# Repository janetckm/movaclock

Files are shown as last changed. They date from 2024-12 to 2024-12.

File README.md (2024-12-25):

# Movaclock： Clock with Movable Type
Project GIF

## Project Description
Movaclock is a clock installation inspired by the Chinese Movable-type system. Using 3D-printed models and mechanisms, Movaclock provides a tangible experience in the RBM Makerspace for time interface and cultural inheritance.

## Slides / About Movaclock 
[https://github.com/janetckm/movaclock/blob/main/powerpoint/movaclock_slides_EN.pdf](https://github.com/janetckm/movaclock/blob/9e4041c35f7cdca07a0c9aedfe9599291e075717/powerpoint/movaclock_slides_EN.pdf)

## Video Demonstration / User Guide
https://youtu.be/eYBHK9oxsUM

## Awards
Second Prize, Red Bird Makerspace Model Maker Compeition, Hong Kong University of Science and Technology (Guangzhou), China <br>
Second Prize, Tsinghua University 3D Competition, Tsinghua University, China

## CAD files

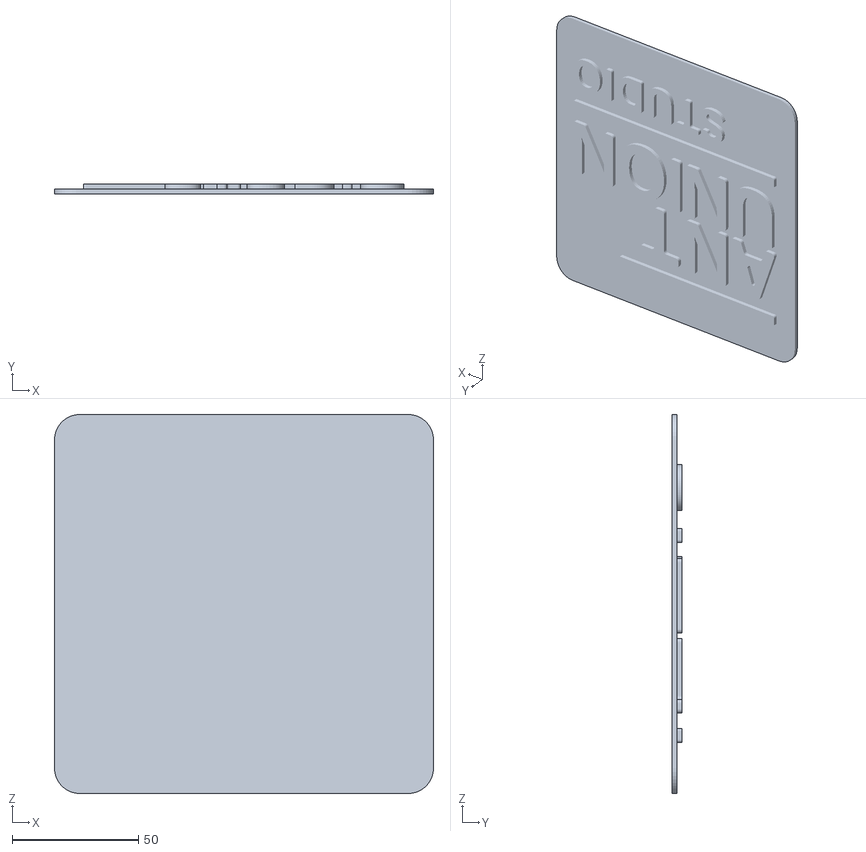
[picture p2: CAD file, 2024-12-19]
logo/printLogo.stl
150.0 x 4.00 x 150.0

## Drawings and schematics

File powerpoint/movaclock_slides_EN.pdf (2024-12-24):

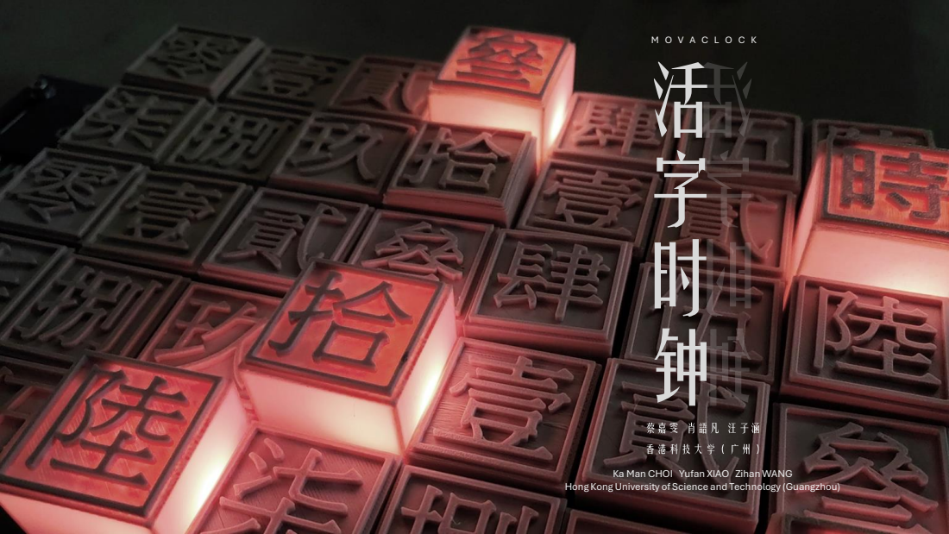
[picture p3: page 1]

Ka Man CHOI Yufan XIAO Zihan WANG

Hong Kong University of Science and Technology (Guangzhou)

背景 与 意义

将 文化传承 带入 日常生活
透过结合当代文创元素融合生活，设计与科技结合可以使传统工艺吸引更 多大眾關注与了解

创新 结合 传统工艺
活字印刷作为非物质文化遗产，结合3D打印和装置艺术，在实现创新的同 时，有助于保护和传承传统工艺

目标与内 容
活字 ＋时钟 ＋灯饰

启发自活字印刷术与2008年北京奥运开幕式的活字升降动态，而时间则 成为文字内容，包括「零、壹、貳、叄、肆、伍、陸、柒、捌、玖、拾」 和「时、分」; 配合灯光和可活动字块的升降，提升时间的可读性

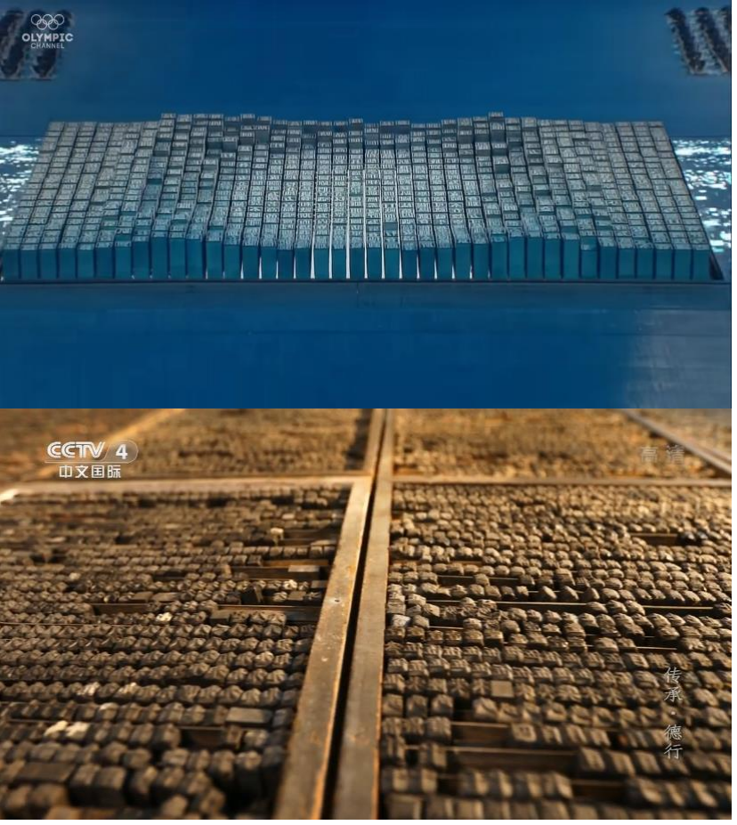
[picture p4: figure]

1. Opening Ceremony - Beijing 2008 Summer Olympic Games
2. [传承第二季] 木活字印刷术 | CCTV中文国际 Wood Movable Types, CCTV 4

Living Word + Clock + Lighting
Inspired by the movable type printing system and the opening ceremony of the 2008 Beijing Olympics, the movable type was developed with controlled movements, while the time becomes the content of the text, including "zero, one, two, two, four, five, six, seven, eight, nine, nine, ten" and "hour, minute“. With the lighting and the up and down of movable types, the readability of time is enhanced.

Objective
Movable Type + Clock + Light

Culture Interpretation

Bringing Cultural Heritage to Daily
Through the integration of cultural elements into daily life, the combination of design and technology can make traditional craftsmanship attract more public understanding
Technology and Craftsmanship
As an intangible cultural heritage, movable type combined with 3D printing and installation art can help convey traditional craftsmanship

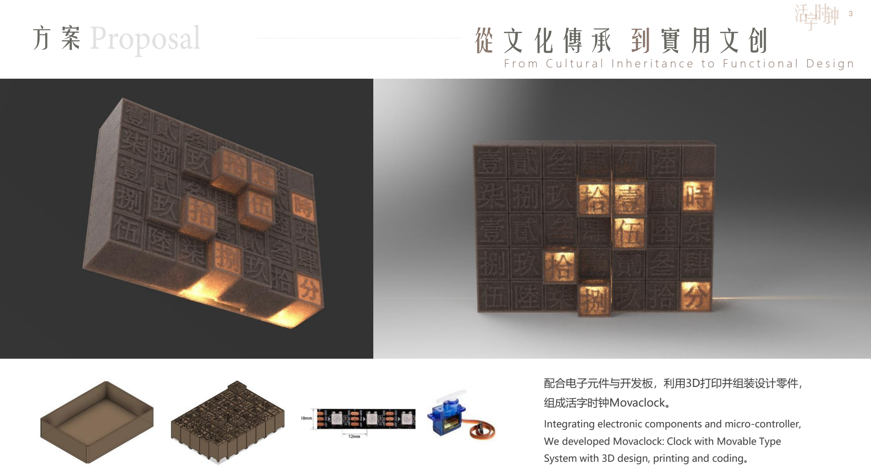
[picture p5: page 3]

配合电子元件与开发板，利用3D打印并组装设计零件，
组成活字时钟Movaclock。

Integrating electronic components and micro-controller, We developed Movaclock: Clock with Movable Type System with 3D design, printing and coding。

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

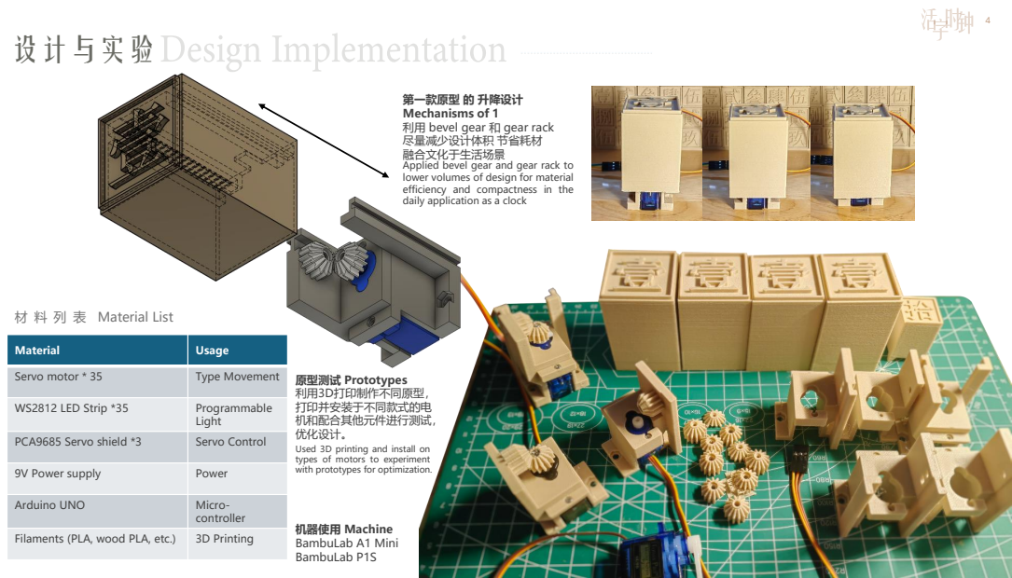
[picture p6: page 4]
机器使用 Machine BambuLab A1 Mini BambuLab P1S; Material List

第一款原型 的 升降设计
Mechanisms of 1
利用 bevel gear 和 gear rack
尽量减少设计体积 节省耗材
融合文化于生活场景
Applied bevel gear and gear rack to
lower volumes of design for material
efficiency and compactness in the
daily application as a clock

Material | Usage

Servo motor＊35 | Type Movement

原型测试 Prototypes
利用3D打印制作不同原型，
打印并安装于不同款式的电
机和配合其他元件进行测试，
优化设计。
Used 3D printing and install on
types of motors to experiment
with prototypes for optimization.

WS2812 LED Strip *35 | Programmable Light

PCA9685 Servo shield *3 | Servo Control

9V Power supply | Power

Arduino UNO | Micro-controller

Filaments (PLA, wood PLA, etc.) | 3D Printing

## PETG

## Wood PLA

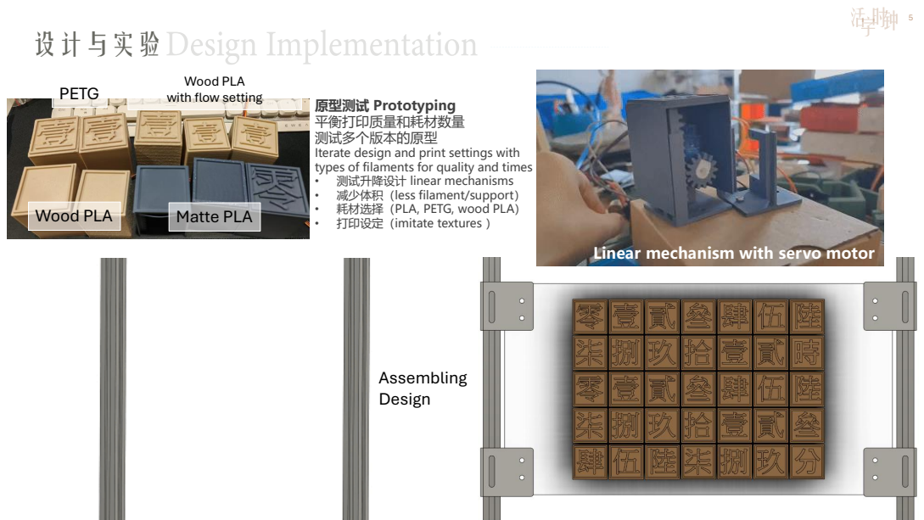
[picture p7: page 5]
耗材选择（PLA, PETG, wood PLA） Wood PLA; Matte PLA; 打印设定（imitate textures ）; Assembling Design

with flow setting

原型测试 Prototyping
平衡打印质量和耗材数量
测试多个版本的原型
Iterate design and print settings with
types of filaments for quality and times
• 测试升降设计 linear mechanisms
• 减少体积（less filament/support）

Linear mechanism with servo motor

## Arduino controls LEDs and motors to change the movements and effects

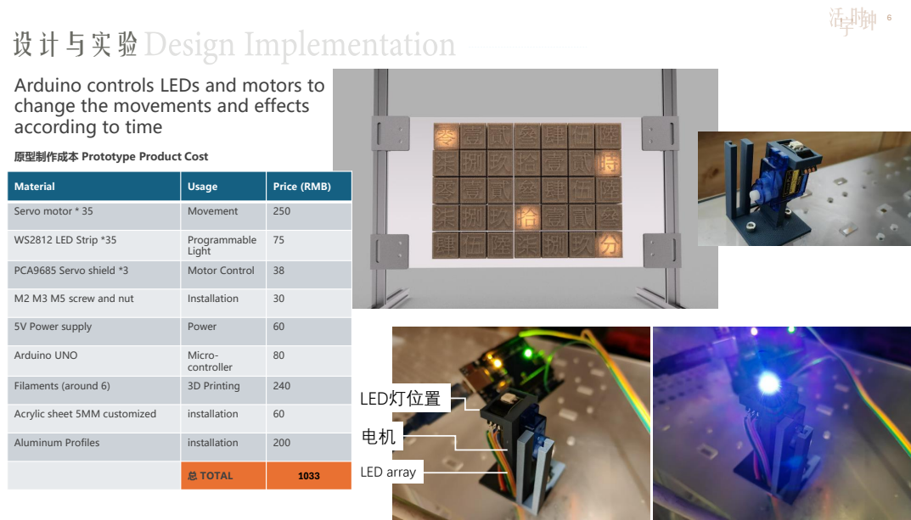
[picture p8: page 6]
原型制作成; LED灯位置; LED array

according to time

本 Prototype Product Cost

Material | Usage | Price (RMB)

Servo motor ＊35 | Movement | 250

WS2812 LED Strip *35 | Programmable Light | 75

PCA9685 Servo shield *3 | Motor Control | 38

M2 M3 M5 screw and nut | Installation | 30

5V Power supply | Power | 60

Arduino UNO | Micro -controller | 80

Filaments (around 6) | 3D Printing | 240

Acrylic sheet 5MM customized | installation | 60

Aluminum Profiles | installation | 200 总 TOTAL 1033

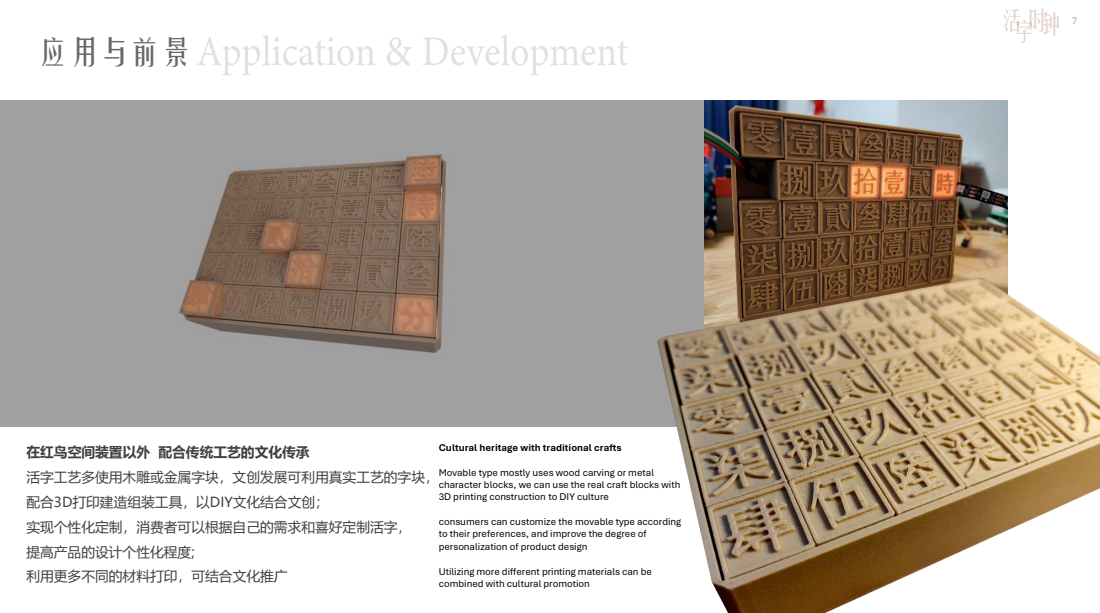
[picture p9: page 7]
在红鸟空间装置以外 配合传统工艺的文化传承; 活字工艺多使用木雕或金属字块，文创发展可利用真实工艺的字块，; 配合3D打印建造组装工具，以DIY文化结合文创；; 实现个性化定制，消费者可以根据自己的需求和喜好定制活字，; 提高产品的设计个性化程度;; 利用更多不同的材料打印，可结合文化推广

Cultural heritage with traditional crafts

Movable type mostly uses wood carving or metal
character blocks, we can use the real craft blocks with
3D printing construction to DIY culture

consumers can customize the movable type according
to their preferences, and improve the degree of
personalization of product design

Utilizing more different printing materials can be
combined with cultural promotion

# 35 LEDs = 0 - 34

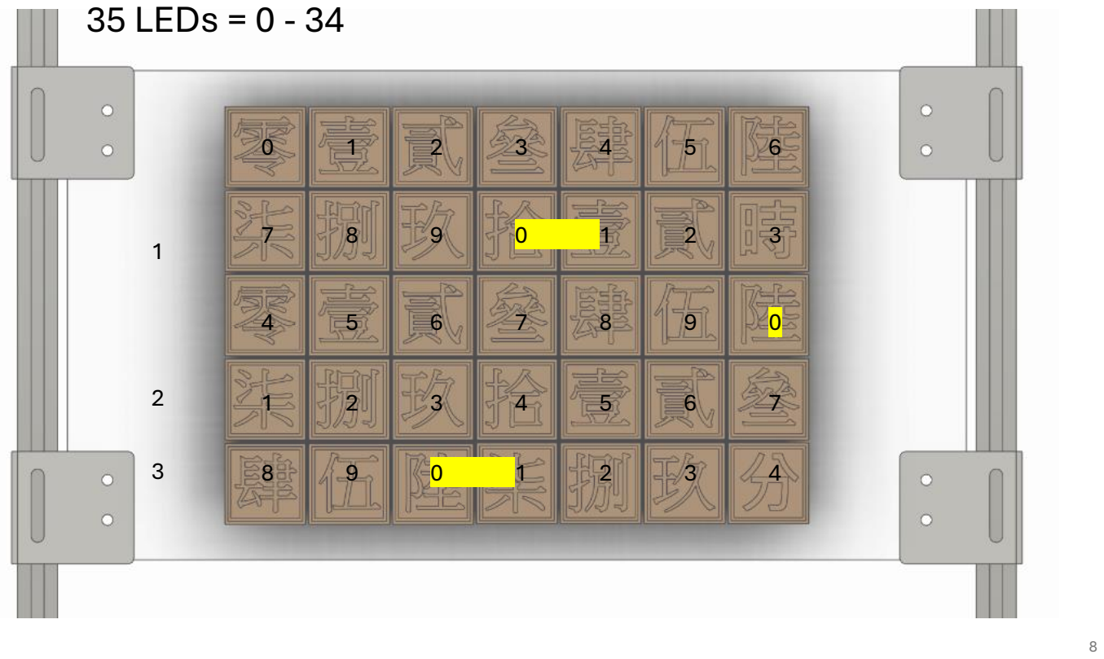
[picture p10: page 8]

0 | 1 | 2 | 3 | 4 | 5 | 6
4 | 5 | 6 | 7 | 8 | 9 | 0
1 | 2 | 3 | 4 | 5 | 6 | 7
7 | 8 | 9 | 0 | 1 | 2 | 3
8 | 9 | 0 | 1 | 2 | 3 | 4

1

2

3
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

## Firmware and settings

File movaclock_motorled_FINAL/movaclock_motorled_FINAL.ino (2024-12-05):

//20241201 MOVACLOCK - Ka Man CHOI JANET

//Chinese Word Clock https://www.instructables.com/Chinese-Word-Clock
//Arduino + Neopixel Word Clock - Super Make Something Episode 6 https://www.youtube.com/watch?v=6tMTQ7Khe90

/***************************************************
  This is an example for our Adafruit 16-channel PWM & Servo driver
  Servo test - this will drive 8 servos, one after the other on the
  first 8 pins of the PCA9685

  Pick one up today in the adafruit shop!
  ------> http://www.adafruit.com/products/815

  These drivers use I2C to communicate, 2 pins are required to
  interface.

  Adafruit invests time and resources providing this open source code,
  please support Adafruit and open-source hardware by purchasing
  products from Adafruit!

  Written by Limor Fried/Ladyada for Adafruit Industries.
  BSD license, all text above must be included in any redistribution
 ****************************************************/

#include <Time.h>
#include <TimeLib.h>


#include <SoftwareSerial.h>
SoftwareSerial SwSerial(10, 11);  // RX, TX

#include <Adafruit_NeoPixel.h>
#ifdef __AVR__
#include <avr/power.h> // Required for 16 MHz Adafruit Trinket
#endif

#define PIN 3
#define NUMPIXELS 35
Adafruit_NeoPixel pixels = Adafruit_NeoPixel(NUMPIXELS, PIN, NEO_GRB + NEO_KHZ800);
#define MINUSFIVEMINS 4
#define PLUSFIVEMINS 5
#define BUTTONLEDMINUS_GND1 8
#define BUTTONLEDMINUS_GND2 9
#define BUTTONLEDPLUS_GND1 10
#define BUTTONLEDPLUS_GND2 11
#define BUTTONLEDMINUS_5V1 A0
#define BUTTONLEDMINUS_5V2 A1
#define BUTTONLEDPLUS_5V1 A2
#define BUTTONLEDPLUS_5V2 A3
int minusPrevState = HIGH;
int minusCurrState = HIGH;
int plusPrevState = HIGH;
int plusCurrState = HIGH;
// Time variables
int h;
int m;
int s;
// RGB color variables
int red = 255;
int green = 255;
int blue = 255;



#include <Wire.h>
#include <Adafruit_PWMServoDriver.h>

// 3 pcs of PCA9685
Adafruit_PWMServoDriver pwm = Adafruit_PWMServoDriver(0x40);
Adafruit_PWMServoDriver pwm2 = Adafruit_PWMServoDriver(0x41);
Adafruit_PWMServoDriver pwm3 = Adafruit_PWMServoDriver(0x42);

#define TOTAL_SERVOS 35
// Array to keep track of current servo states
// 0 = DOWN, 1 = UP
bool servoStates[TOTAL_SERVOS] = {0};

#define SERVOMIN  150 // This is the 'minimum' pulse length count (out of 4096) HIGHEST TEXT
#define SERVOMAX  500 // This is the 'maximum' pulse length count (out of 4096) LOWEST TEXT

#define UP  200 // This is the 'minimum' pulse length count (out of 4096) HIGHEST TEXT
#define DOWN  500 // This is the 'maximum' pulse length count (out of 4096) LOWEST TEXT
#define USMIN  1200 // This is the rounded 'minimum' microsecond length based on the minimum pulse of 150
#define puttype  600 // highest for putting the type
#define upclock  1200 // highest for clock
#define USMAX  2000 // This is the rounded 'maximum' microsecond length based on the maximum pulse of 600
#define downclock  2000 // lowest for clock
#define SERVO_FREQ 50 // Analog servos run at ~50 Hz updates

// our servo # counter
uint8_t servonum = 0;
uint8_t servonumMAX = 16;

void setup() {
  Serial.begin(9600);
  Serial.println("8 channel Servo test!");

  pwm.begin();
  pwm2.begin();
  pwm3.begin();
  pixels.begin();

  pwm.setOscillatorFrequency(27000000);
  pwm.setPWMFreq(SERVO_FREQ);  // Analog servos run at ~50 Hz updates

  pwm2.setOscillatorFrequency(27000000);
  pwm2.setPWMFreq(SERVO_FREQ);  // Analog servos run at ~50 Hz updates

  pwm3.setOscillatorFrequency(27000000);
  pwm3.setPWMFreq(SERVO_FREQ);  // Analog servos run at ~50 Hz updates

  //set time!
  setTime(3, 16, 0, 30, 11, 2024);  //Initialize current time as Midnight/noon 08/31/2015

  pixels.begin();                   //Begin Neopixel string

  delay(10);

  //PIXEL MATRIX
  pixels.clear();
  delay(2000);
  for (int i = NUMPIXELS; i >= 0; i--) { // For each pixel...
    pixels.setPixelColor(i, pixels.Color(255, 255, 255));
    pixels.show();   // Send the updated pixel colors to the hardware.
    delay(10); // Pause before next pass through loop
  }

  // Reset all servos to UP position
  for (int i = 0; i < TOTAL_SERVOS; i++) {
    pwm.setPWM(i, 0, UP);
    pwm2.setPWM(i, 0, UP);
    pwm3.setPWM(i, 0, UP);
    delay(50);
  }

  delay(800);  // Small delay between each servo to prevent power surge

  // Reset all servos to DOWN position
  for (int i = 0; i < TOTAL_SERVOS; i++) {
    pwm.setPWM(i, 0, DOWN);
    pwm2.setPWM(i, 0, DOWN);
    pwm3.setPWM(i, 0, DOWN);
  }

  delay(500);  // Small delay between each servo to prevent power surge

  //PIXEL MATRIX
  pixels.clear();
  delay(2000);
  for (int i = 0; i < NUMPIXELS; i++) { // For each pixel...
    pixels.setPixelColor(i, pixels.Color(255, 255, 255));
    pixels.show();   // Send the updated pixel colors to the hardware.
    delay(100); // Pause before next pass through loop
  }

  delay(2000);
}

void loop() {

  // Drive each servo one at a time using setPWM()
  //DOWN TEXT
  Serial.println(servonum);

  //downtext();
  //uptext();

  movaclock();
}

//function for making the types down
void downtext() {
  for (uint16_t pulselen = SERVOMIN; pulselen < SERVOMAX; pulselen++) {
    pwm.setPWM(servonum, 0, pulselen);
    pwm2.setPWM(servonum, 0, pulselen);
    pwm3.setPWM(servonum, 0, pulselen);
  }

  delay(500);
}

void uptext() {
  for (uint16_t pulselen = SERVOMAX; pulselen > SERVOMIN; pulselen--) {
    pwm.setPWM(servonum, 0, pulselen);
    pwm2.setPWM(servonum, 0, pulselen);
    pwm3.setPWM(servonum, 0, pulselen);
  }

  delay(500);
}

void allup() {
  pwm.setPWM(servonum, 0, UP);
  pwm2.setPWM(servonum, 0, UP);
  pwm3.setPWM(servonum, 0, UP);

  servonum++;
  if (servonum > servonumMAX) servonum = 0; // Testing the first 8 servo channels

}

void alldown() {
  pwm.setPWM(servonum, 0, DOWN);
  pwm2.setPWM(servonum, 0, DOWN);
  pwm3.setPWM(servonum, 0, DOWN);

  servonum++;
  if (servonum > servonumMAX) servonum = 0; // Testing the first 8 servo channels

}

void movaclock() {
  //Declare integer array with size corresponding to number of Neopixels in chain
  int individualPixels[NUMPIXELS] = { 0, 0, 0, 0, 0,
                                      0, 0, 0, 0, 0,
                                      0, 0, 0, 0, 0,
                                      0, 0, 0, 0, 0,
                                      0, 0, 0, 0, 0,
                                      0, 0, 0, 0, 0,
                                      0, 0, 0, 0, 0
                                    };

  /* Check for button presses & reset time if necessary */
  minusCurrState = digitalRead(MINUSFIVEMINS);  //Get current state of MINUSFIVEMINS button
  /* If current state is different from previous state and value is now LOW, subtract five minutes from current time */
  if ((minusCurrState != minusPrevState) && (minusCurrState == LOW)) {
    //adjustTime(-5*60); //Shift time five minutes backwards
    adjustTime(-1 * 60);  //Shift time one minutes backwards

    minusPrevState = minusCurrState;
  } else {
    minusPrevState = minusCurrState;
  }

  /* If current state is different from previous state and value is now LOW, add five minutes from current time */
  if ((plusCurrState != plusPrevState) && (plusCurrState == LOW)) {
    //adjustTime(5 * 60); //Shift time five minutes forwards
    adjustTime(1 * 60);  //Shift time one minutes forwards

    plusPrevState = plusCurrState;
  } else {
    plusPrevState = plusCurrState;
  }

  /* Get current time */
  h = hourFormat12();  // Returns the hour of current time between 1-12
  m = minute();        // Returns the minute of current time
  s = second();        // Returns the second of current time (not used, included for completeness)

  Serial.print(h);
  Serial.print(":");
  Serial.print(m);
  Serial.print(":");
  Serial.println(s);

  /* Parse time values to light corresponding pixels */
  // individualPixels[0] = 1; //Light "IT"
  // individualPixels[1] = 1; //Light "IS"
  individualPixels[13] = 1;  //Light "時"
  pwm.setPWM(13, 0, UP);
  individualPixels[34] = 1;  //Light "分"
  pwm3.setPWM(2, 0, UP);


  // 零時
  if (h == 0) {
    individualPixels[0] = 1;
    pwm.setPWM(0, 0, UP);
  }
  // 壹時
  if (h == 1) {
    individualPixels[1] = 1;
    pwm.setPWM(1, 0, UP);
  }


  if (h == 2) {
    pwm.setPWM(1, 0, DOWN);
    individualPixels[2] = 1;
    pwm.setPWM(2, 0, UP);
  }


  if (h == 3) {
    pwm.setPWM(2, 0, DOWN);
    individualPixels[3] = 1;
    pwm.setPWM(3, 0, UP);
  }


  if (h == 4) {
    pwm.setPWM(3, 0, DOWN);
    individualPixels[4] = 1;
    pwm.setPWM(4, 0, UP);
  }

  if (h == 5) {
    pwm.setPWM(4, 0, DOWN);
    individualPixels[5] = 1;
    pwm.setPWM(5, 0, UP);
  }


  if (h == 6) {
    pwm.setPWM(5, 0, DOWN);
    individualPixels[6] = 1;
    pwm.setPWM(6, 0, UP);
  }

  if (h == 7) {
    pwm.setPWM(6, 0, DOWN);
    individualPixels[7] = 1;
    pwm.setPWM(7, 0, UP);
  }


  if (h == 8) {
    pwm.setPWM(7, 0, DOWN);
    individualPixels[8] = 1;
    pwm.setPWM(8, 0, UP);
  }

  if (h == 9) {
    pwm.setPWM(8, 0, DOWN);
    individualPixels[9] = 1;
    pwm.setPWM(9, 0, UP);
  }

  if (h == 10) {
    pwm.setPWM(9, 0, DOWN);
    individualPixels[10] = 1;
    pwm.setPWM(10, 0, UP);
  }


  if (h == 11) {
    individualPixels[10] = 1;
    individualPixels[11] = 1;
    pwm.setPWM(11, 0, UP);
  }

  if (h == 12) {
    pwm.setPWM(11, 0, DOWN);
    individualPixels[10] = 1;
    individualPixels[12] = 1;
    pwm.setPWM(10, 0, UP);
    pwm.setPWM(12, 0, UP);
  }

  //END of hour



  //START of minutes 零壹分
  if (m == 0) {
    pwm2.setPWM(8, 0, DOWN);
    pwm2.setPWM(3, 0, DOWN);
    pwm3.setPWM(1, 0, DOWN);
    individualPixels[14] = 1;
    pwm.setPWM(14, 0, UP);
  }

  if (m == 1) {
    pwm2.setPWM(8, 0, DOWN);
    individualPixels[14] = 1;
    individualPixels[15] = 1;
    pwm.setPWM(14, 0, UP);
    pwm.setPWM(15, 0, UP);
  }

  if (m == 2) {
    pwm.setPWM(15, 0, DOWN);
    individualPixels[14] = 1;
    individualPixels[16] = 1;
    pwm.setPWM(14, 0, UP);
    pwm2.setPWM(0, 0, UP);
  }


  if (m == 3) {
    pwm2.setPWM(0, 0, DOWN);
    individualPixels[14] = 1;
    individualPixels[17] = 1;
    pwm.setPWM(14, 0, UP);
    pwm2.setPWM(1, 0, UP);
  }

  if (m == 4) {
    pwm2.setPWM(1, 0, DOWN);
    individualPixels[14] = 1;
    individualPixels[18] = 1;
    pwm.setPWM(14, 0, UP);
    pwm2.setPWM(2, 0, UP);
  }

  if (m == 5) {
    pwm2.setPWM(2, 0, DOWN);
    individualPixels[14] = 1;
    individualPixels[19] = 1;
    pwm.setPWM(14, 0, UP);
    pwm2.setPWM(3, 0, UP);
  }

  if (m == 6) {
    pwm2.setPWM(3, 0, DOWN);
    individualPixels[14] = 1;
    individualPixels[20] = 1;
    pwm.setPWM(14, 0, UP);
    pwm2.setPWM(4, 0, UP);
  }

  if (m == 7) {
    pwm2.setPWM(4, 0, DOWN);
    individualPixels[14] = 1;
    individualPixels[21] = 1;
    pwm.setPWM(14, 0, UP);
    pwm2.setPWM(5, 0, UP);
  }

  if (m == 8) {
    pwm2.setPWM(5, 0, DOWN);
    individualPixels[14] = 1;
    individualPixels[22] = 1;
    pwm.setPWM(14, 0, UP);
    pwm2.setPWM(6, 0, UP);
  }

  if (m == 9) {
    pwm2.setPWM(6, 0, DOWN);
    individualPixels[14] = 1;
    individualPixels[23] = 1;
    pwm.setPWM(14, 0, UP);
    pwm2.setPWM(7, 0, UP);
  }

  if (m == 10) {
    pwm.setPWM(14, 0, DOWN);
    pwm2.setPWM(7, 0, DOWN);
    individualPixels[24] = 1;
    pwm2.setPWM(8, 0, UP);
  }


  if (m == 11) {
    individualPixels[24] = 1;
    individualPixels[25] = 1;
    pwm2.setPWM(8, 0, UP);
    pwm2.setPWM(9, 0, UP);
  }

  if (m == 12) {
    pwm2.setPWM(9, 0, DOWN);
    individualPixels[24] = 1;
    individualPixels[26] = 1;
    pwm2.setPWM(8, 0, UP);
    pwm2.setPWM(10, 0, UP);
  }

  if (m == 13) {
    pwm2.setPWM(10, 0, DOWN);
    individualPixels[24] = 1;
    individualPixels[27] = 1;
    pwm2.setPWM(8, 0, UP);
    pwm2.setPWM(11, 0, UP);
  }

  if (m == 14) {
    pwm2.setPWM(11, 0, DOWN);
    individualPixels[24] = 1;
    individualPixels[28] = 1;
    pwm2.setPWM(8, 0, UP);
    pwm2.setPWM(12, 0, UP);
  }

  if (m == 15) {
    pwm2.setPWM(12, 0, DOWN);
    individualPixels[24] = 1;
    individualPixels[29] = 1;
    pwm2.setPWM(8, 0, UP);
    pwm2.setPWM(13, 0, UP);
  }

  if (m == 16) {
    pwm2.setPWM(13, 0, DOWN);
    individualPixels[24] = 1;
    individualPixels[30] = 1;
    pwm2.setPWM(8, 0, UP);
    pwm2.setPWM(14, 0, UP);
  }

  if (m == 17) {
    pwm2.setPWM(14, 0, DOWN);
    individualPixels[24] = 1;
    individualPixels[31] = 1;
    pwm2.setPWM(8, 0, UP);
    pwm2.setPWM(15, 0, UP);
  }

  if (m == 18) {
    pwm2.setPWM(15, 0, DOWN);
    individualPixels[24] = 1;
    individualPixels[32] = 1;
    pwm2.setPWM(8, 0, UP);
    pwm3.setPWM(0, 0, UP);
  }

  if (m == 19) {
    pwm3.setPWM(0, 0, DOWN);
    individualPixels[24] = 1;
    individualPixels[33] = 1;
    pwm2.setPWM(8, 0, UP);
    pwm3.setPWM(1, 0, UP);
  }
  //20

  if (m == 20) {
    pwm3.setPWM(1, 0, DOWN);
    individualPixels[16] = 1;
    individualPixels[24] = 1;
    pwm2.setPWM(0, 0, UP);
    pwm2.setPWM(8, 0, UP);
  }

  if (m == 21) {
    individualPixels[16] = 1;
    individualPixels[24] = 1;
    individualPixels[25] = 1;
    pwm2.setPWM(0, 0, UP);
    pwm2.setPWM(8, 0, UP);
    pwm2.setPWM(9, 0, UP);
  }

  if (m == 22) {
    pwm2.setPWM(9, 0, DOWN);
    individualPixels[16] = 1;
    individualPixels[24] = 1;
    individualPixels[26] = 1;
    pwm2.setPWM(0, 0, UP);
    pwm2.setPWM(8, 0, UP);
    pwm2.setPWM(10, 0, UP);
  }

  if (m == 23) {
    pwm2.setPWM(10, 0, DOWN);
    individualPixels[16] = 1;
    individualPixels[24] = 1;
    individualPixels[27] = 1;
    pwm2.setPWM(0, 0, UP);
    pwm2.setPWM(8, 0, UP);
    pwm2.setPWM(11, 0, UP);
  }

  if (m == 24) {
    pwm2.setPWM(11, 0, DOWN);
    individualPixels[16] = 1;
    individualPixels[24] = 1;
    individualPixels[28] = 1;
    pwm2.setPWM(0, 0, UP);
    pwm2.setPWM(8, 0, UP);
    pwm2.setPWM(12, 0, UP);
  }

  if (m == 25) {
    pwm2.setPWM(12, 0, DOWN);
    individualPixels[16] = 1;
    individualPixels[24] = 1;
    individualPixels[29] = 1;
    pwm2.setPWM(0, 0, UP);
    pwm2.setPWM(8, 0, UP);
    pwm2.setPWM(13, 0, UP);
  }

  if (m == 26) {
    pwm2.setPWM(13, 0, DOWN);
    individualPixels[16] = 1;
    individualPixels[24] = 1;
    individualPixels[30] = 1;
    pwm2.setPWM(0, 0, UP);
    pwm2.setPWM(8, 0, UP);
    pwm2.setPWM(14, 0, UP);
  }

  if (m == 27) {
    pwm2.setPWM(14, 0, DOWN);
    individualPixels[16] = 1;
    individualPixels[24] = 1;
    individualPixels[31] = 1;
    pwm2.setPWM(0, 0, UP);
    pwm2.setPWM(8, 0, UP);
    pwm2.setPWM(15, 0, UP);
  }

  if (m == 28) {
    pwm2.setPWM(15, 0, DOWN);
    individualPixels[16] = 1;
    individualPixels[24] = 1;
    individualPixels[32] = 1;
    pwm2.setPWM(0, 0, UP);
    pwm2.setPWM(8, 0, UP);
    pwm3.setPWM(0, 0, UP);
  }

  if (m == 29) {
    pwm3.setPWM(0, 0, DOWN);
    individualPixels[16] = 1;
    individualPixels[24] = 1;
    individualPixels[33] = 1;
    pwm2.setPWM(0, 0, UP);
    pwm2.setPWM(8, 0, UP);
    pwm3.setPWM(1, 0, UP);
  }

  //30
  if (m == 30) {
    pwm2.setPWM(0, 0, DOWN);
    pwm3.setPWM(1, 0, DOWN);
    individualPixels[17] = 1;
    individualPixels[24] = 1;
    pwm2.setPWM(1, 0, UP);
    pwm2.setPWM(8, 0, UP);
  }

  if (m == 31) {
    individualPixels[17] = 1;
    individualPixels[24] = 1;
    individualPixels[25] = 1;
    pwm2.setPWM(1, 0, UP);
    pwm2.setPWM(8, 0, UP);
    pwm2.setPWM(9, 0, UP);
  }

  if (m == 32) {
    pwm2.setPWM(9, 0, DOWN);
    individualPixels[17] = 1;
    individualPixels[24] = 1;
    individualPixels[26] = 1;
    pwm2.setPWM(1, 0, UP);
    pwm2.setPWM(8, 0, UP);
    pwm2.setPWM(10, 0, UP);
  }

  if (m == 33) {
    pwm2.setPWM(10, 0, DOWN);
    individualPixels[17] = 1;
    individualPixels[24] = 1;
    individualPixels[27] = 1;
    pwm2.setPWM(1, 0, UP);
    pwm2.setPWM(8, 0, UP);
    pwm2.setPWM(11, 0, UP);
  }

  if (m == 34) {
    pwm2.setPWM(11, 0, DOWN);
    individualPixels[17] = 1;
    individualPixels[24] = 1;
    individualPixels[28] = 1;
    pwm2.setPWM(1, 0, UP);
    pwm2.setPWM(8, 0, UP);
    pwm2.setPWM(12, 0, UP);
  }

  if (m == 35) {
    pwm2.setPWM(12, 0, DOWN);
    individualPixels[17] = 1;
    individualPixels[24] = 1;
    individualPixels[29] = 1;
    pwm2.setPWM(1, 0, UP);
    pwm2.setPWM(8, 0, UP);
    pwm2.setPWM(13, 0, UP);
  }

  if (m == 36) {
    pwm2.setPWM(13, 0, DOWN);
    individualPixels[17] = 1;
    individualPixels[24] = 1;
    individualPixels[30] = 1;
    pwm2.setPWM(1, 0, UP);
    pwm2.setPWM(8, 0, UP);
    pwm2.setPWM(14, 0, UP);
  }

  if (m == 37) {
    pwm2.setPWM(14, 0, DOWN);
    individualPixels[17] = 1;
    individualPixels[24] = 1;
    individualPixels[31] = 1;
    pwm2.setPWM(1, 0, UP);
    pwm2.setPWM(8, 0, UP);
    pwm2.setPWM(15, 0, UP);
  }

  if (m == 38) {
    pwm2.setPWM(15, 0, DOWN);
    individualPixels[17] = 1;
    individualPixels[24] = 1;
    individualPixels[32] = 1;
    pwm2.setPWM(1, 0, UP);
    pwm2.setPWM(8, 0, UP);
    pwm3.setPWM(0, 0, UP);
  }

  if (m == 39) {
    pwm3.setPWM(0, 0, DOWN);
    individualPixels[17] = 1;
    individualPixels[24] = 1;
    individualPixels[33] = 1;
    pwm2.setPWM(1, 0, UP);
    pwm2.setPWM(8, 0, UP);
    pwm3.setPWM(1, 0, UP);
  }

  //40
  if (m == 40) {
    pwm2.setPWM(1, 0, DOWN);
    pwm3.setPWM(1, 0, DOWN);
    individualPixels[18] = 1;
    individualPixels[24] = 1;
    pwm2.setPWM(2, 0, UP);
    pwm2.setPWM(8, 0, UP);
  }

  if (m == 41) {
    individualPixels[18] = 1;
    individualPixels[24] = 1;
    individualPixels[25] = 1;
    pwm2.setPWM(2, 0, UP);
    pwm2.setPWM(8, 0, UP);
    pwm2.setPWM(9, 0, UP);
  }

  if (m == 42) {
    pwm2.setPWM(9, 0, DOWN);
    individualPixels[18] = 1;
    individualPixels[24] = 1;
    individualPixels[26] = 1;
    pwm2.setPWM(2, 0, UP);
    pwm2.setPWM(8, 0, UP);
    pwm2.setPWM(10, 0, UP);
  }

  if (m == 43) {
    pwm2.setPWM(10, 0, DOWN);
    individualPixels[18] = 1;
    individualPixels[24] = 1;
    individualPixels[27] = 1;
    pwm2.setPWM(2, 0, UP);
    pwm2.setPWM(8, 0, UP);
    pwm2.setPWM(11, 0, UP);
  }

  if (m == 44) {
    pwm2.setPWM(11, 0, DOWN);
    individualPixels[18] = 1;
    individualPixels[24] = 1;
    individualPixels[28] = 1;
    pwm2.setPWM(2, 0, UP);
    pwm2.setPWM(8, 0, UP);
    pwm2.setPWM(12, 0, UP);
  }

  if (m == 45) {
    pwm2.setPWM(12, 0, DOWN);
    individualPixels[18] = 1;
    individualPixels[24] = 1;
    individualPixels[29] = 1;
    pwm2.setPWM(2, 0, UP);
    pwm2.setPWM(8, 0, UP);
    pwm2.setPWM(13, 0, UP);
  }

  if (m == 46) {
    pwm2.setPWM(13, 0, DOWN);
    individualPixels[18] = 1;
    individualPixels[24] = 1;
    individualPixels[30] = 1;
    pwm2.setPWM(2, 0, UP);
    pwm2.setPWM(8, 0, UP);
    pwm2.setPWM(14, 0, UP);
  }

  if (m == 47) {
    pwm2.setPWM(14, 0, DOWN);
    individualPixels[18] = 1;
    individualPixels[24] = 1;
    individualPixels[31] = 1;
    pwm2.setPWM(2, 0, UP);
    pwm2.setPWM(8, 0, UP);
    pwm2.setPWM(15, 0, UP);
  }

  if (m == 48) {
    pwm2.setPWM(15, 0, DOWN);
    individualPixels[18] = 1;
    individualPixels[24] = 1;
    individualPixels[32] = 1;
    pwm2.setPWM(2, 0, UP);
    pwm2.setPWM(8, 0, UP);
    pwm3.setPWM(0, 0, UP);
  }

  if (m == 49) {
    pwm3.setPWM(0, 0, DOWN);
    individualPixels[18] = 1;
    individualPixels[24] = 1;
    individualPixels[33] = 1;
    pwm2.setPWM(2, 0, UP);
    pwm2.setPWM(8, 0, UP);
    pwm3.setPWM(1, 0, UP);
  }

  //50
  if (m == 50) {
    pwm2.setPWM(2, 0, DOWN);
    pwm3.setPWM(1, 0, DOWN);
    individualPixels[19] = 1;
    individualPixels[24] = 1;
    pwm2.setPWM(3, 0, UP);
    pwm2.setPWM(8, 0, UP);
  }

  if (m == 51) {
    individualPixels[19] = 1;
    individualPixels[24] = 1;
    individualPixels[25] = 1;
    pwm2.setPWM(3, 0, UP);
    pwm2.setPWM(8, 0, UP);
    pwm2.setPWM(9, 0, UP);
  }

  if (m == 52) {
    pwm2.setPWM(9, 0, DOWN);
    individualPixels[19] = 1;
    individualPixels[24] = 1;
    individualPixels[26] = 1;
    pwm2.setPWM(3, 0, UP);
    pwm2.setPWM(8, 0, UP);
    pwm2.setPWM(10, 0, UP);
  }

  if (m == 53) {
    pwm2.setPWM(10, 0, DOWN);
    individualPixels[19] = 1;
    individualPixels[24] = 1;
    individualPixels[27] = 1;
    pwm2.setPWM(3, 0, UP);
    pwm2.setPWM(8, 0, UP);
    pwm2.setPWM(11, 0, UP);
  }

  if (m == 54) {
    pwm2.setPWM(11, 0, DOWN);
    individualPixels[19] = 1;
    individualPixels[24] = 1;
    individualPixels[28] = 1;
    pwm2.setPWM(3, 0, UP);
    pwm2.setPWM(8, 0, UP);
    pwm2.setPWM(12, 0, UP);
  }

  if (m == 55) {
    pwm2.setPWM(12, 0, DOWN);
    individualPixels[19] = 1;
    individualPixels[24] = 1;
    individualPixels[29] = 1;
    pwm2.setPWM(3, 0, UP);
    pwm2.setPWM(8, 0, UP);
    pwm2.setPWM(13, 0, UP);
  }

  if (m == 56) {
    pwm2.setPWM(13, 0, DOWN);
    individualPixels[19] = 1;
    individualPixels[24] = 1;
    individualPixels[30] = 1;
    pwm2.setPWM(3, 0, UP);
    pwm2.setPWM(8, 0, UP);
    pwm2.setPWM(14, 0, UP);
  }

  if (m == 57) {
    pwm2.setPWM(14, 0, DOWN);
    individualPixels[19] = 1;
    individualPixels[24] = 1;
    individualPixels[31] = 1;
    pwm2.setPWM(3, 0, UP);
    pwm2.setPWM(8, 0, UP);
    pwm2.setPWM(15, 0, UP);
  }

  if (m == 58) {
    pwm2.setPWM(15, 0, DOWN);
    individualPixels[19] = 1;
    individualPixels[24] = 1;
    individualPixels[32] = 1;
    pwm2.setPWM(3, 0, UP);
    pwm2.setPWM(8, 0, UP);
    pwm3.setPWM(0, 0, UP);
  }

  if (m == 59) {
    pwm3.setPWM(0, 0, DOWN);
    individualPixels[19] = 1;
    individualPixels[24] = 1;
    individualPixels[33] = 1;
    pwm2.setPWM(3, 0, UP);
    pwm2.setPWM(8, 0, UP);
    pwm3.setPWM(1, 0, UP);
  }

  /* Light pixels corresponding to current time */
  for (int i = 0; i < sizeof(individualPixels); i++) {
    if (individualPixels[i] == 1) {
      pixels.setPixelColor(i, pixels.Color(red, green, blue));  //Set Neopixel color
    } else {
      pixels.setPixelColor(i, pixels.Color(0, 0, 0));
    }
  }

  pixels.show();  //Display Neopixel color
}
